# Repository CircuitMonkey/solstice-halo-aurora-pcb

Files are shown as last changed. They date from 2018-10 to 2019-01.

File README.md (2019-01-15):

# solstice-core-starfire-pcb
Solstice Design System —  *Aurora* HaLo —  Eagle PCB

PCB files for the **Circuit Monkey** *Aurora* **Solstice** *HaLo*

Format is EagleCAD 9.x schematic and board layout

*Aurora* is a *Solstice* Hardware Locus (HaLo) module/shield.  The Aurora allows you to add a prototyping perf-board to the top of your Solstice Core module.

For more details, check out the product page at

  * https://www.tindie.com/products/15591/

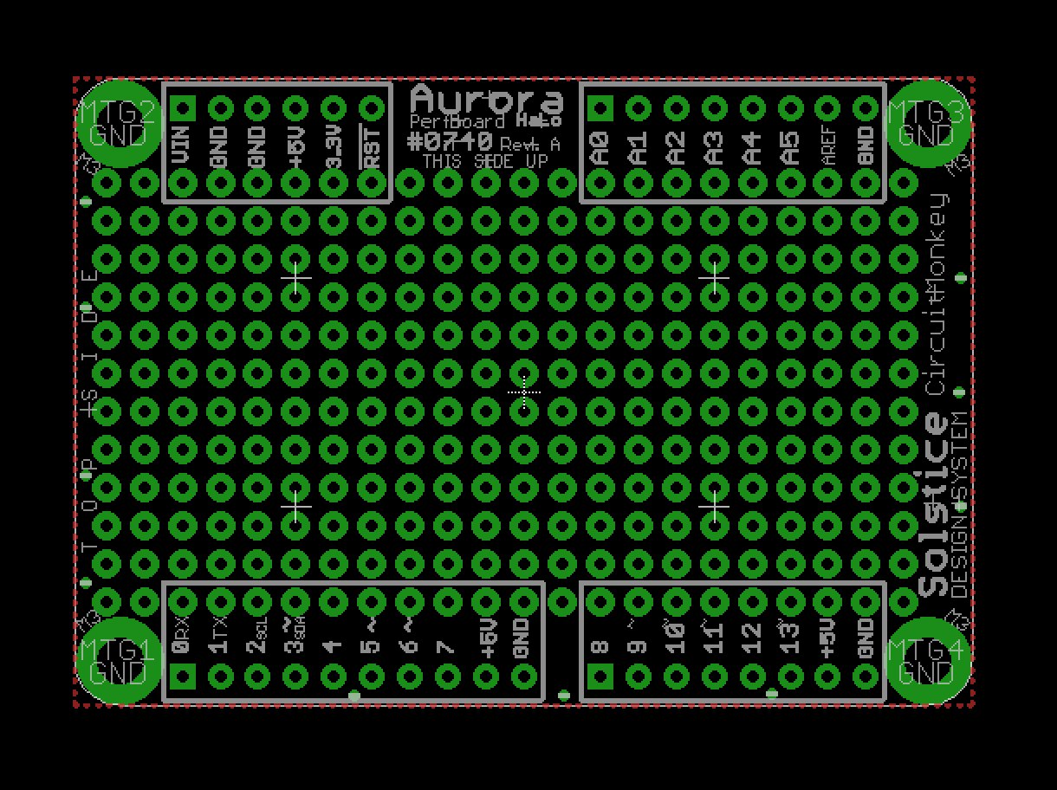
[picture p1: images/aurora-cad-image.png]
PCB CAD Image


### Revision Notes
* Rev. 0 - Initial board design.  This revision was made for evaluation and only
one unit ever made.  Not shared in this repository.

* Rev. A - First revision meant for human consumption.

* Rev. B - Fixed Vin and GND pins swapped. First for-sale version.

#### Rev A. Issues:
  * Forgot to swap Vin and GND pins on HaLo connector.   Vin was dangerously close to GND mounting hole.  Was swapped on core StarFire board but we goofed in updating the Rev. A design for this board.  Solution for now is to pluck connector pins 1 and 2 out of HL4 passthrough connector prior to soldering.  Also, black sharpie the legend for those to pins.  Attempting to use these pins would short Vin to GND.

#### Rev B. Issues:
    * No known issues.

## Designed by Circuit Monkey in Las Vegas, Nevada, USA
MIT License.

All text above must be included in any redistribution

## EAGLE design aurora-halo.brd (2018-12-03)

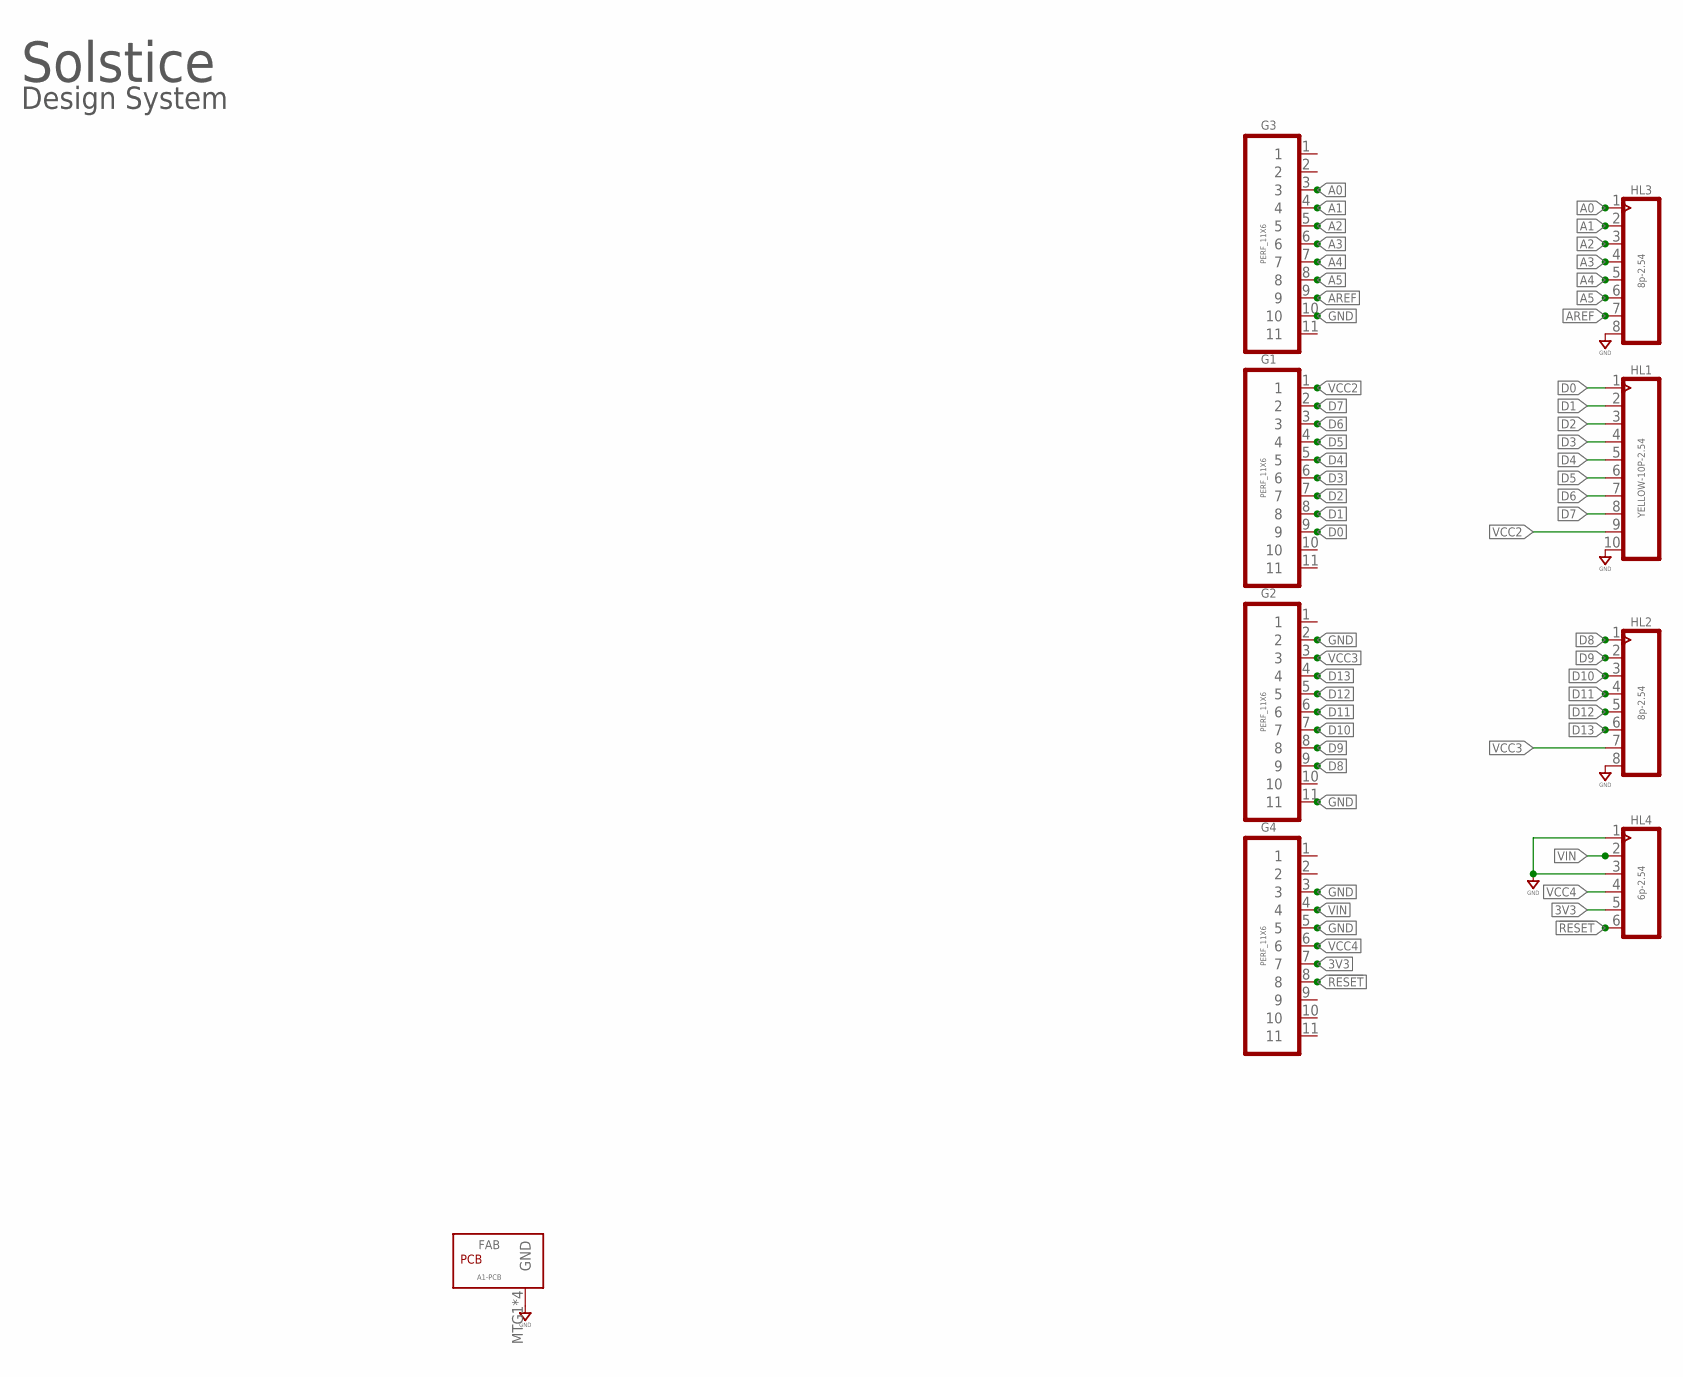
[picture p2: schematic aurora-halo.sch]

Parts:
FAB: A1-PCB; PCB-HALO-A1
G1, G2, G3, G4: PERF_11X6; PERF_6X11
HL1: YELLOW-10P-2.54; H10-2.54
HL2, HL3: 8p-2.54; H8-2.54
HL4: 6p-2.54; H6-2.54

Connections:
3V3: G4.7, HL4.5
!RESET: G4.8, HL4.6
A0: G3.3, HL3.1
A1: G3.4, HL3.2
A2: G3.5, HL3.3
A3: G3.6, HL3.4
A4: G3.7, HL3.5
A5: G3.8, HL3.6
AREF: G3.9, HL3.7
D0: G1.9, HL1.1
D1: G1.8, HL1.2
D2: G1.7, HL1.3
D3: G1.6, HL1.4
D4: G1.5, HL1.5
D5: G1.4, HL1.6
D6: G1.3, HL1.7
D7: G1.2, HL1.8
D8: G2.9, HL2.1
D9: G2.8, HL2.2
D10: G2.7, HL2.3
D11: G2.6, HL2.4
D12: G2.5, HL2.5
D13: G2.4, HL2.6
GND: FAB.MTG1, FAB.MTG2, FAB.MTG3, FAB.MTG4, G2.2, G2.11, G3.10, G4.3, G4.5, HL1.10, HL2.8, HL3.8, HL4.1, HL4.3
VCC2: G1.1, HL1.9
VCC3: G2.3, HL2.7
VCC4: G4.6, HL4.4
VIN: G4.4, HL4.2

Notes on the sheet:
Solstice
Design System

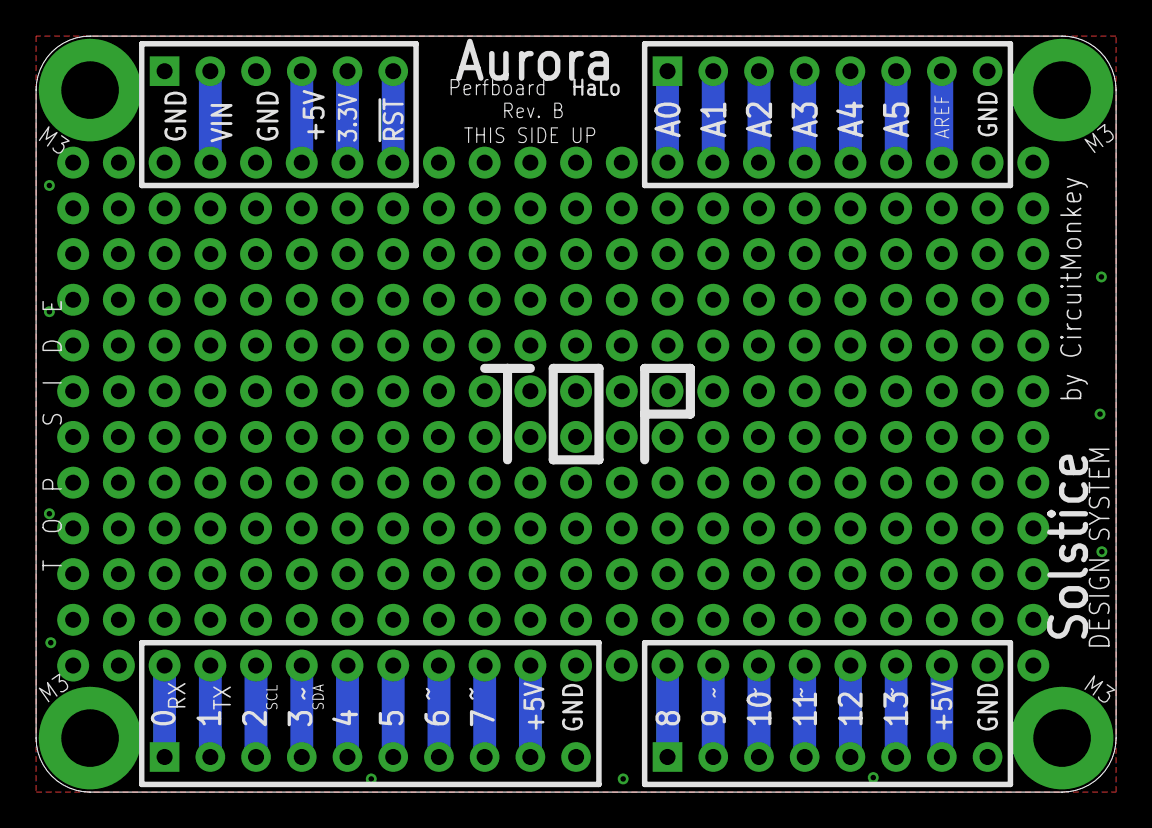
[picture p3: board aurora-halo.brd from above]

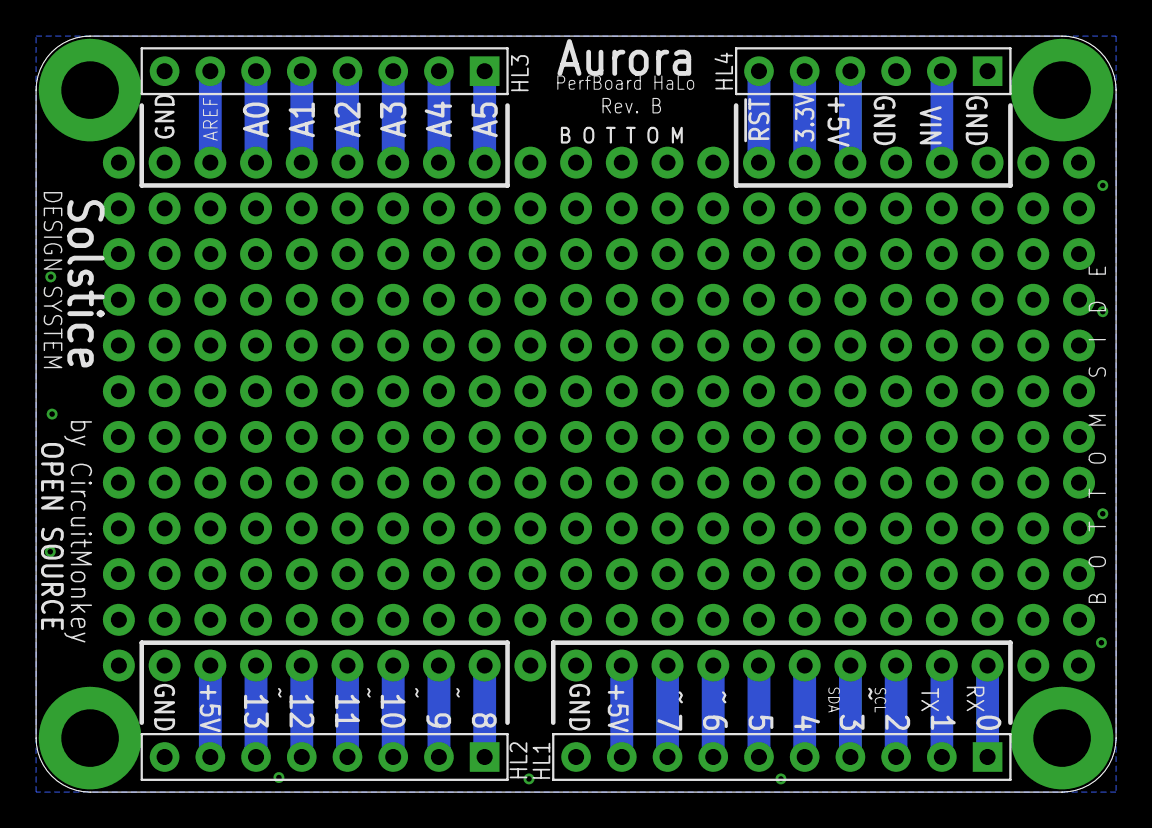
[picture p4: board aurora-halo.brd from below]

Board: 2 copper layers, 60.0 x 42.0 mm, 9 parts (4 on the bottom side), 28 nets.

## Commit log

2018-10-30 Publish Aurora HaLo Rev. A PCB.
    [aurora-halo.brd, aurora-halo.sch]
2018-10-31 Update README.md
    License is MIT. Copy/paste goof from Solstice Core readme.md, which is Creative Commons because it was derived from Arduino. Our HaLo boards are not Arduino derivative in design.
2018-12-03 Update PCB to Rev. B
    [aurora-halo.brd, aurora-halo.sch]
